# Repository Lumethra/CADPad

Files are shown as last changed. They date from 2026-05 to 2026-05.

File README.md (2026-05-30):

# CADPad

## What is this?? 

SHHH, this is a gift, dont spoiler it, SHHHH. But what exactly is this?? Good question. Its a keyboard. Again. Wait, what does again mean, well its my second one. My [Auth75](https://github.com/Lumethra/Auth75) was my first one. Back to what this is. Its technically a keyboard, but I would rather call it a Macropad, because its firmwares purpose is to make 3d modeling in Onshape easier. This is also why its called a CADPad, not Catpad (meow), CADPad. C A D, like CAD-design. 

### Features: 
  - custom 27 keys leyout
      - its kinda ergonomic? kinda.
  - Nice!Nano V2
      - ZMK firmware (hand written, yeeeeee)
      - better ZMK support, because Nice!Nano V2
      - build in BLE support
      - LiPo battery support
      - battery charger + support
  - USB Hub (SL2.1)
      - 1 USB-C upsream
      - 4 USB-C donwstreams
      - USB 2.0 fullspeed

---

## Why though?

This is a gift to [Chroma](https://github.com/Chroma165), my friend who likes to design 3d-models and print them with his 3d-printer. I though it would be nice to gift him a Macropad, my bad, its a CADPad, to make this process easier for him. It was also fun to design a PCB, that has a unique form. 

---

## How?

This CADPads development process was fairly easiy because of the knowledge from Auth75. It has 3 layers of keybinds, which u can cycle through with pressing the 2nd knob. The other knobs keypress is reserved for BLE pairing. 

---

## Renders

| PCB with Components |
| --- |
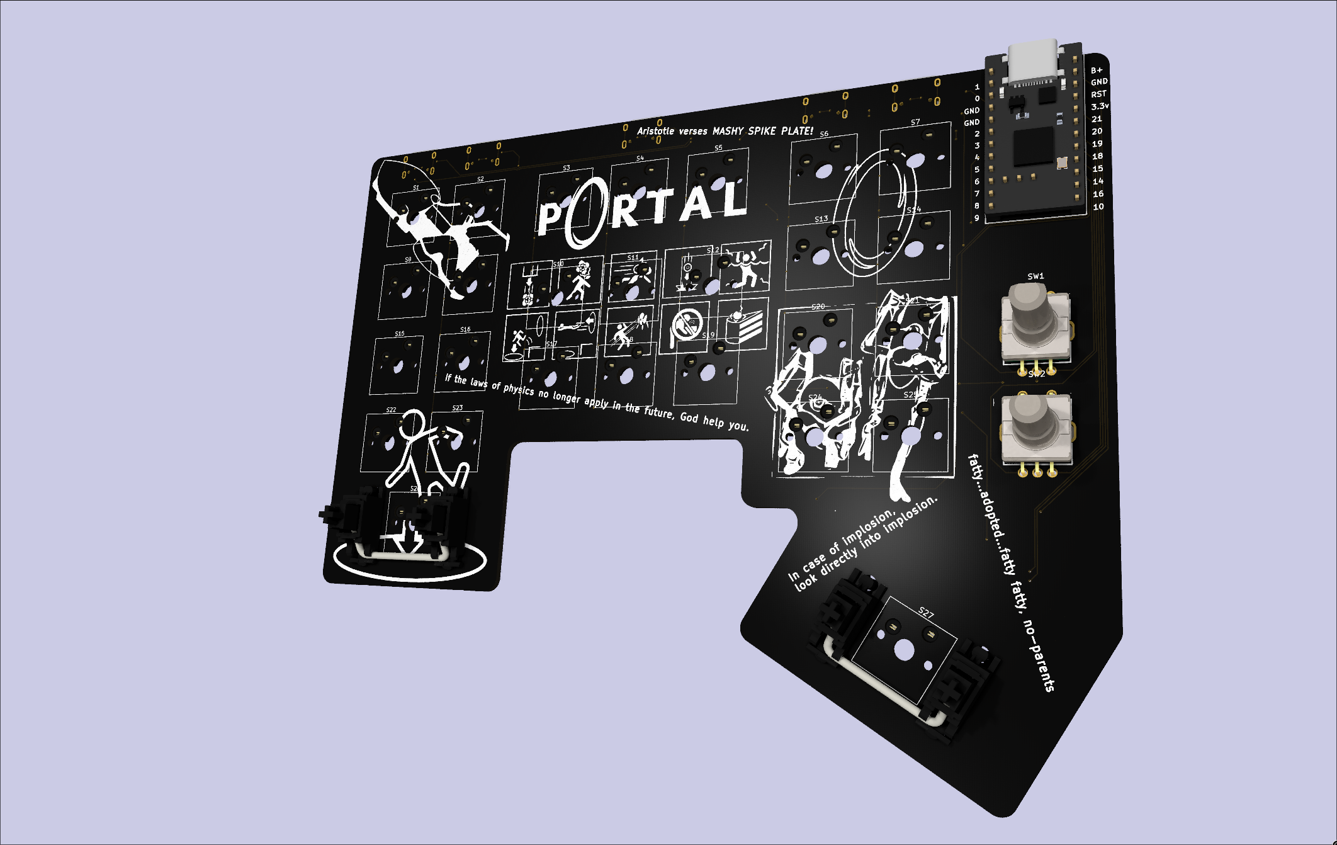
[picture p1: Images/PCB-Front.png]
PCB Front
|  |
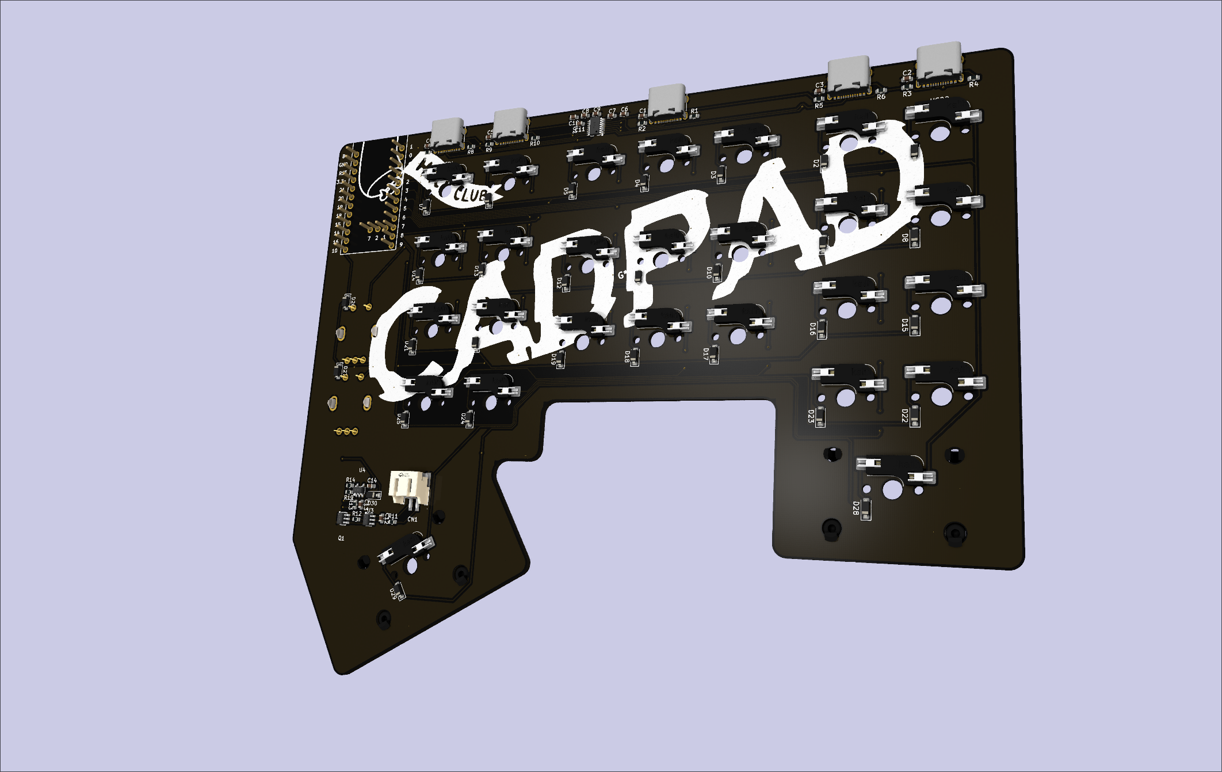
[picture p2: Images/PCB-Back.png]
|  |

| PCB without Components |
| --- |
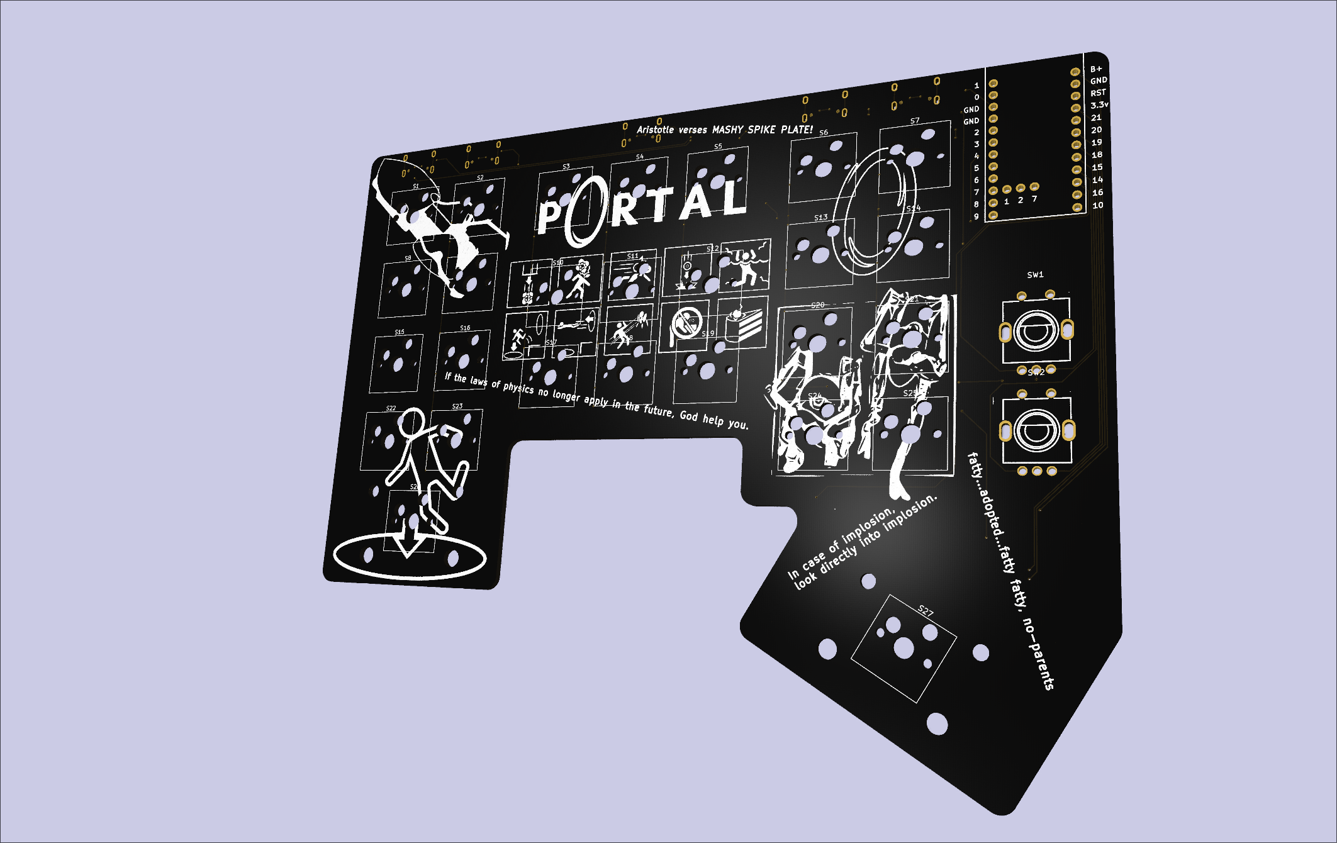
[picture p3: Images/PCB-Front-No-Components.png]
PCB Front
|  |
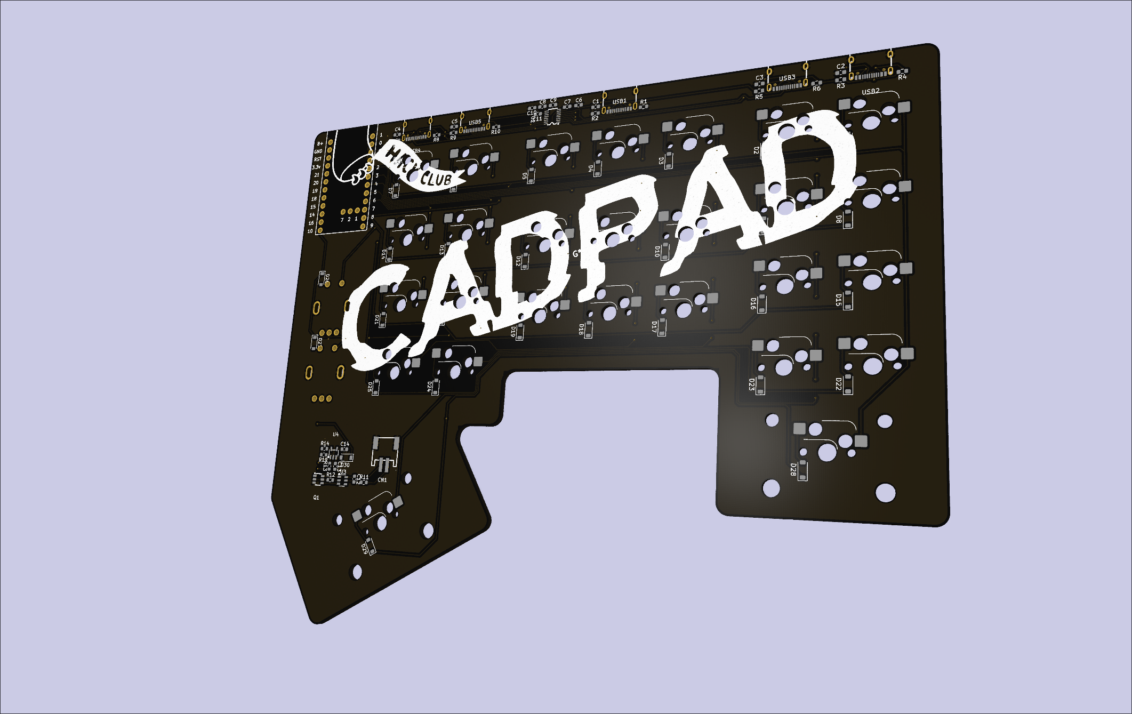
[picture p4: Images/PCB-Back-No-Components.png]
|  |

| Case |
| --- |
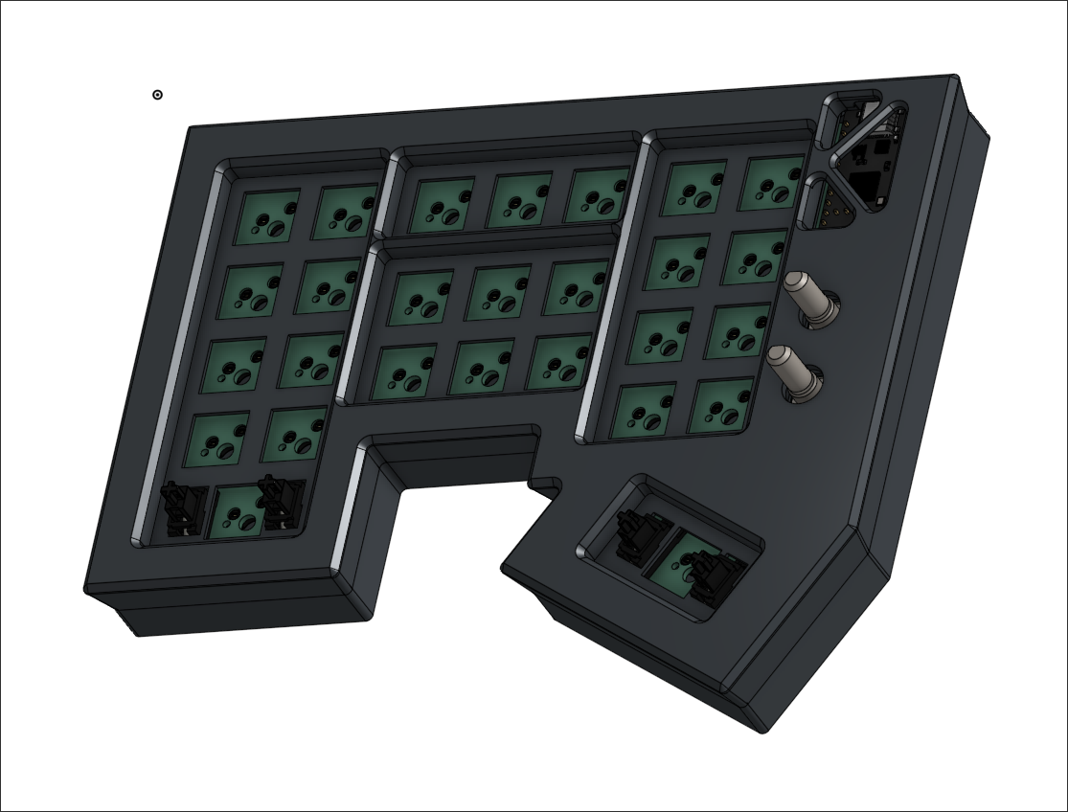
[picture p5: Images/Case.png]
|  |

---

## PCB + Schematics

| PCB |
| --- |
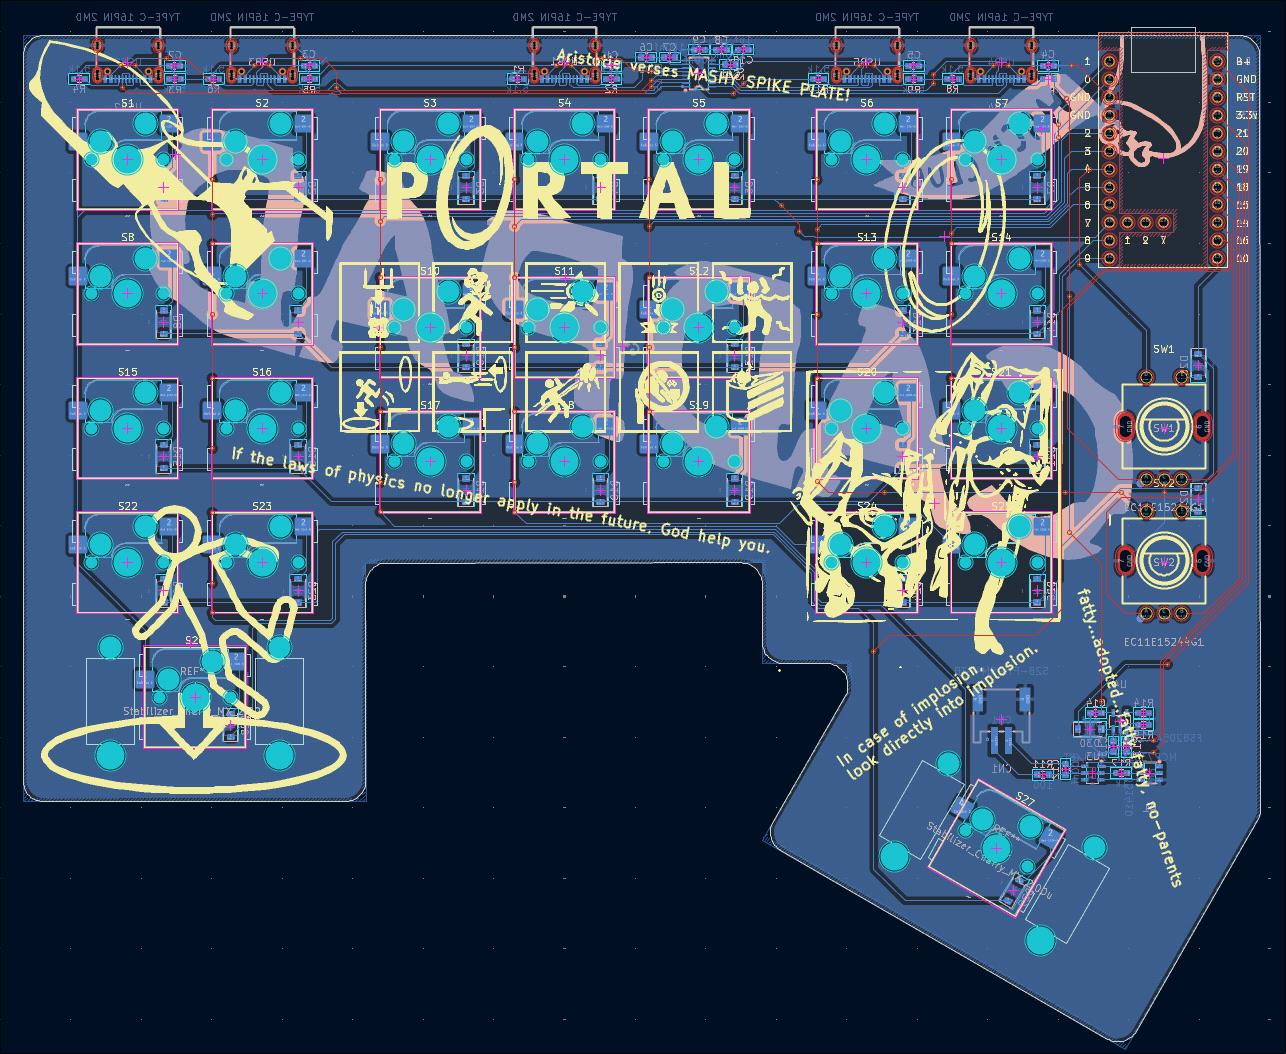
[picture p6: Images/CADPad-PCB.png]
CADPad PCB
|  |

| Schematics |
| --- |
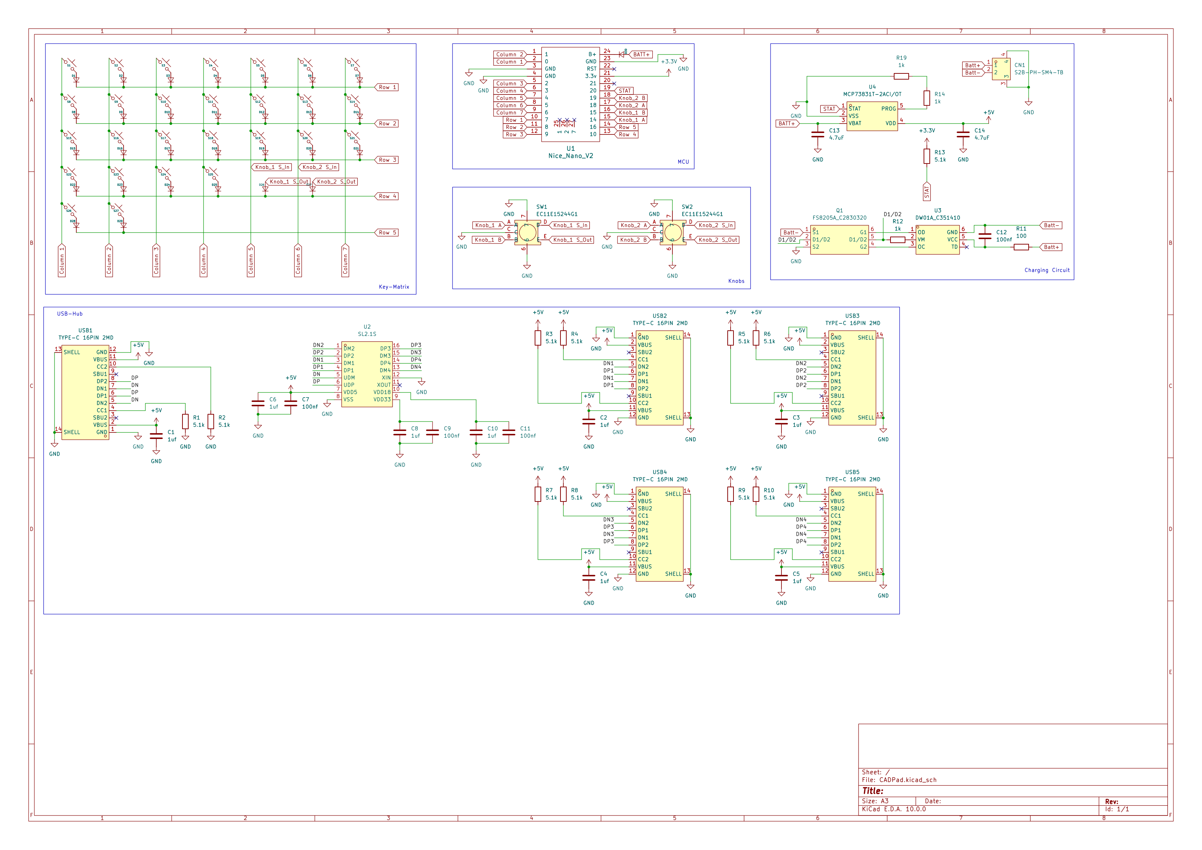
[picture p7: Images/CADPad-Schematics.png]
CADPad Schematics
|  |

---

<details>
  <summary>
    <h2>Zine</h2> 
  </summary>

| Zine |
| --- |
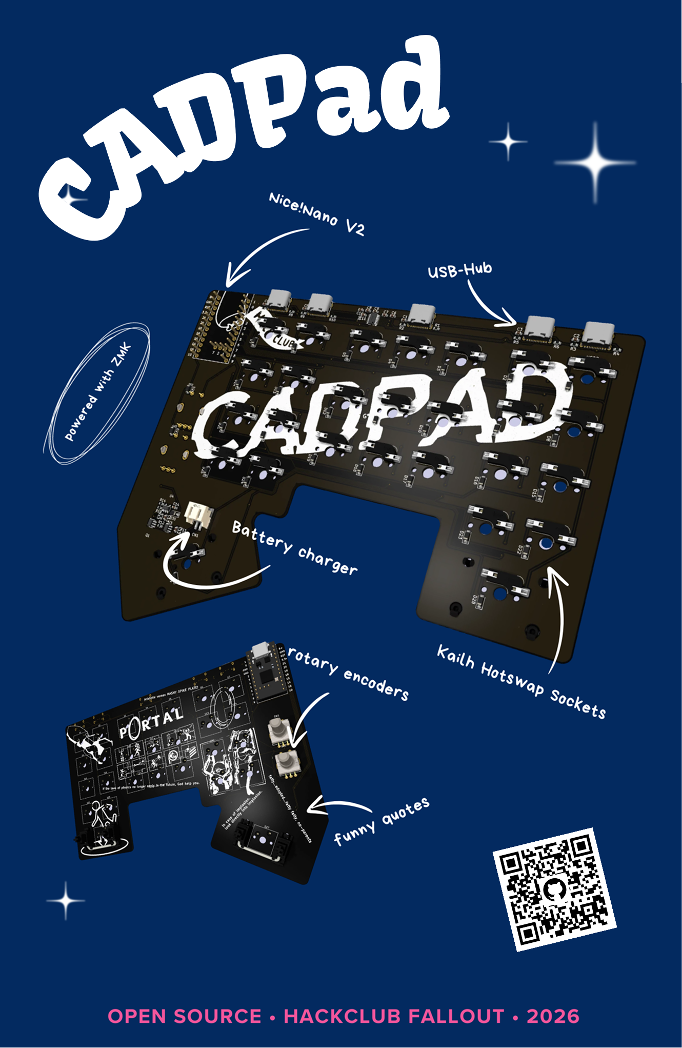
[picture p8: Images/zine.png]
CADPad Zine
|  |

---
</details>

## BOM

| Part | Purpose | Cost | Quantity | Total Cost | LCSC/JLCPC Number | Link |
| --- | --- | --- | --- | --- | --- | --- |
| PCB | connect all of the compoenents | $14.10 | 1 (5) | $14.10 | ~ | [JLCPCB](https://jlcpcb.com/) |
| Nice!Nano V2 | handle the firmware | €24.63 | 1 | €24.63 | ~ | [42keebs](https://42keebs.eu/shop/parts/controllers/nice-nano-v2-wireless-controller/) | 
| Kailh Hotswap Sockets | holding the switches to the PCB without soldering | $0.1183 | 78 | ~$9 | C2803348 | [JLCPCB](https://jlcpcb.com/partdetail/C2803348) |
| Kailh (Cocoa) Switches | the switches you can press | $0 (comes with a Rainy75) | 78 | $0 (already owned) | ~ | ~ |
| Keycaps | goes onto the switches for better look and feel | $0 (3d printing ABS) | 78 | $0 (3d printed) | ~ | ~ |
| EC11 Rotary Encoder Switch | goes uii and click click | $2.22 | 1 | $2.22 | C370970 | [JLCPCB](https://jlcpcb.com/partdetail/C370970) / [Amazon](https://www.amazon.de/-/en/RUNCCI-YUN-Potentiometer-Automotive-Electronics-Multimedia/dp/B09SG3HF9N) |
| USB-C connector | connect to laptop | $0.0740 | 4 | $0.296 | C2765186 | [JLCPCB](https://jlcpcb.com/partdetail/C2765186) |
| SL2.1s | USB Hub core component | $0.2258 | 1 | $0.2258 | C2684433 | [JLCPCB](https://jlcpcb.com/partdetail/C2684433) |
| DW01A | battery protector | $0.0426 | 1 | $0.0426 | C351410 | [JLCPCB](https://jlcpcb.com/partdetail/C351410) |
| FS8205A | mosfet for protector | $0.0470 | 1 | $0.0470 | C2830320 | [JLCPCB](https://jlcpcb.com/partdetail/C2830320) |
| S2B-PH-SM4-TB | LiPo battery connector | $0.2014 | 1 | $0.2014 | C295747 | [JLCPCB](https://jlcpcb.com/partdetail/C295747) |
| Diodes | prevent voltage from backflowing and causing problems | $0.0117 | 82 | ~$0.9594 | C81598 | [JLCPCB](https://jlcpcb.com/partdetail/C81598) |
| Resistors | prevent things go boom | ~$0.0016 | 19 | ~$0.0304 | C23186, C21190, C22775 | [C23186](https://jlcpcb.com/partdetail/C23186) / [C21190](https://jlcpcb.com/partdetail/C21190) / [C22775](https://jlcpcb.com/partdetail/C22775) |
| Capacitors | smooth out the power | $0.0032 - $0.0110 | 14 | ~$0.0956 | C15849, C19666, C14663 | [C15849](https://jlcpcb.com/partdetail/C15849) / [C19666](https://jlcpcb.com/partdetail/C19666) / [C14663](https://jlcpcb.com/partdetail/C14663) |

> the prices can vary depending on the provider <br>
> you can find the JLCPCB parts on [LCSC](https://lcsc.com/) too (exept the PCB and the Pico)

--- 

## Contribute

Want to make anything better? Found any bugs? Anything always going booom?? Feel free to open a PR (pull request) and lets make the project better. ^_^
> the libraries are all imported with [easyeda2kicad](https://github.com/uPesy/easyeda2kicad.py) and [kiswitch](https://github.com/kiswitch/kiswitch)

---

## Thank you

A huge thank you too all these persons helping me making this project possible, thank you helping me sanity check, thank you for all these support. 
> Thank you, <3 u all ^_^

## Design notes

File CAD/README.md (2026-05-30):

Case source files are here

https://cad.onshape.com/documents/18ff7c1247dc01870b6e44be/w/b77948019c848fef9af64c41/e/35ab0d3820c1c6a5cbac0af8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

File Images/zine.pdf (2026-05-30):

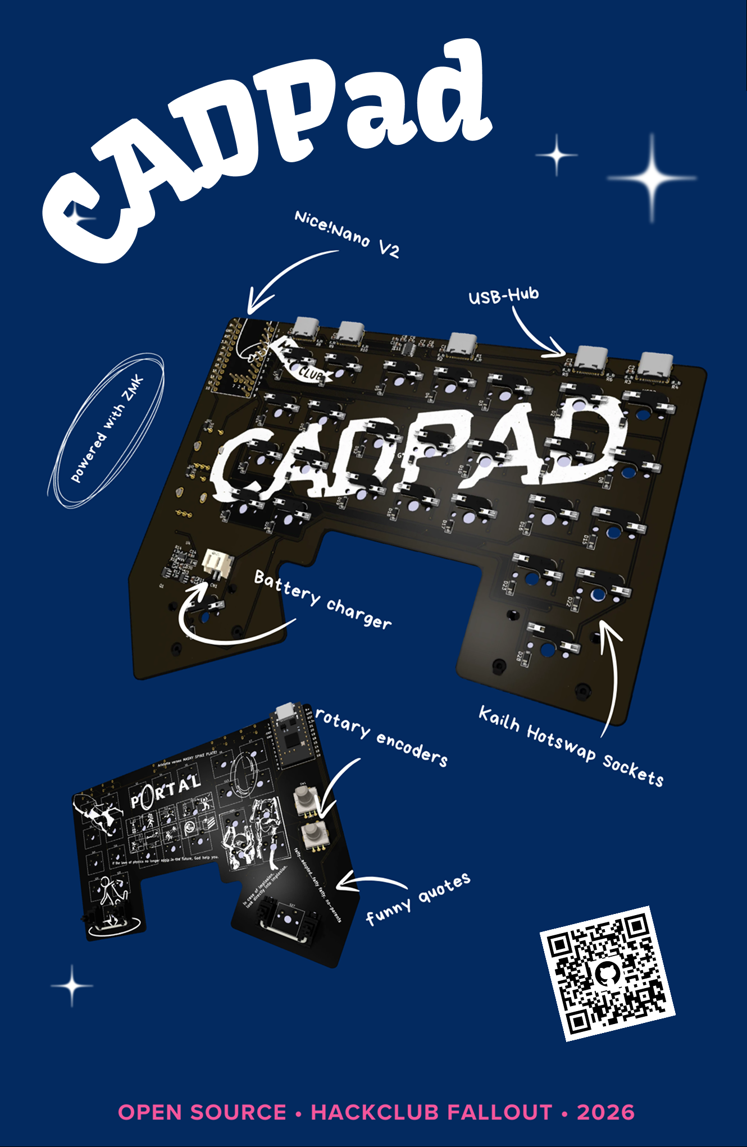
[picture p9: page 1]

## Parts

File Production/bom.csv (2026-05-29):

Name | Designator | Footprint | Quantity | Value | Price | LCSC Part # | Purchase Link
Capacitors 1uF | C1, C10, C2, C3, C4, C5, C6, C8 | 0603 | 8 | 1uF | $0.0032 | C15849 | https://jlcpcb.com/partdetail/C15849
Capacitors 100nF | C11, C12, C7, C9 | 0603 | 4 | 100nF | $0.0032 | C14663 | https://jlcpcb.com/partdetail/C14663
Capacitors 4.7uF | C13, C14 | 0603 | 2 | 4.7uF | $0.0110 | C19666 | https://jlcpcb.com/partdetail/C19666
S2B-PH-SM4-TB | CN1 | CONN-SMD_P2.00_S2B-PH-SM4-TB-LF-SN | 1 | S2B-PH-SM4-TB | $0.2014 | C295747 | https://jlcpcb.com/partdetail/C295747
Diodes | D1, D10, D11, D12, D13, D14, D15, D16, D17, D18, D19, D2, D20, D21, D22, D23, D24, D25, D26, D27, D28, D29, D3, D30, D4, D5, D6, D7, D8, D9 | D_SOD-123 | 30 | ~ | $0.0117 | C81598 | https://jlcpcb.com/partdetail/C81598
FS8205A | Q1 | SOT-23-6_L2.9-W1.6-P0.95-LS2.8-BR | 1 | FS8205A_C2830320 | $0.0470 | C2830320 | https://jlcpcb.com/partdetail/C2830320
Resistors 5.1k | R1, R10, R13, R2, R3, R4, R5, R6, R7, R8, R9 | 0603 | 11 | 5.1k | $0.0016 | C23186 | https://jlcpcb.com/partdetail/C23186
Resistors 100 | R11 | 0603 | 1 | 100 | $0.0016 | C22775 | https://jlcpcb.com/partdetail/C22775
Resistors 1k | R12, R14, R19 | 0603 | 3 | 1k | $0.0016 | C21190 | https://jlcpcb.com/partdetail/C21190
Kailh Hotswap Sockets | S1, S10, S11, S12, S13, S14, S15, S16, S17, S18, S19, S2, S20, S21, S22, S23, S24, S25, S26, S27, S3, S4, S5, S6, S7, S8, S9 | SW_Hotswap_Kailh_MX | 27 | ~ | $0.1183 | C2803348 | https://jlcpcb.com/partdetail/C2803348
Nice Nano V2 | U1 | Nice_Nano_V2 | 1 | Nice_Nano_V2 | €24.63 | ~ | https://42keebs.eu/shop/parts/controllers/nice-nano-v2-wireless-controller/
SL2.1S | U2 | SSOP-16_L4.6-W2.6-P0.53-LS4.0-BL | 1 | SL2.1S | $0.2258 | C2684433 | https://jlcpcb.com/partdetail/C2684433
DW01A | U3 | SOT-23-6_L2.9-W1.6-P0.95-LS2.8-BL | 1 | DW01A_C351410 | $0.0426 | C351410 | https://jlcpcb.com/partdetail/C351410
MCP73831T-2ACI/OT | U4 | SOT-23-5_L3.0-W1.7-P0.95-LS2.8-BL | 1 | MCP73831T-2ACI/OT | $0.7585 | C424093 | https://jlcpcb.com/partdetail/C424093
USB-C Connector | USB1, USB2, USB3, USB4, USB5 | USB-C-SMD_TYPE-C-6PIN-2MD-073 | 5 | TYPE-C 16PIN 2MD | $0.0740 | C2765186 | https://jlcpcb.com/partdetail/C2765186

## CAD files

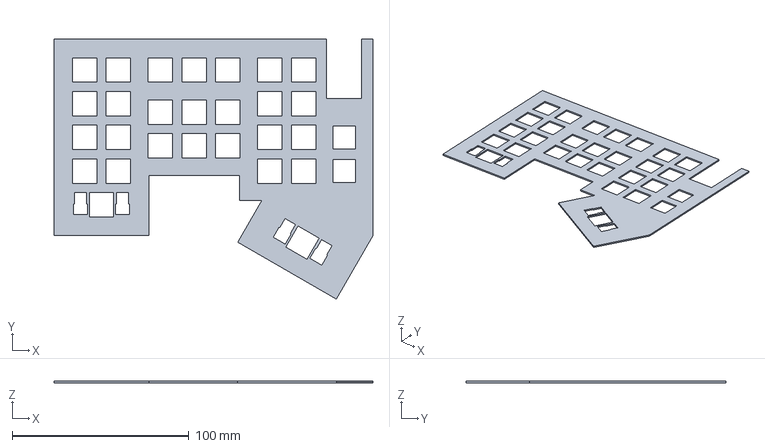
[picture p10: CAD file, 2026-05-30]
CAD/Case/CadPadSwitchPlate.step
180.4 x 147.2 x 1.00 mm

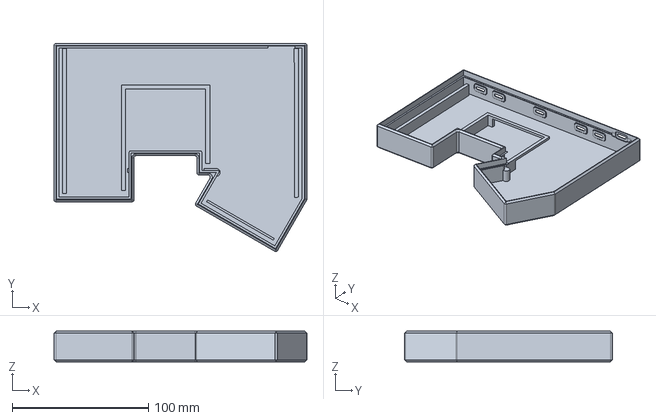
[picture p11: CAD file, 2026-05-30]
CAD/Case/CadPadBottomHalf.step
185.4 x 152.6 x 22.4 mm

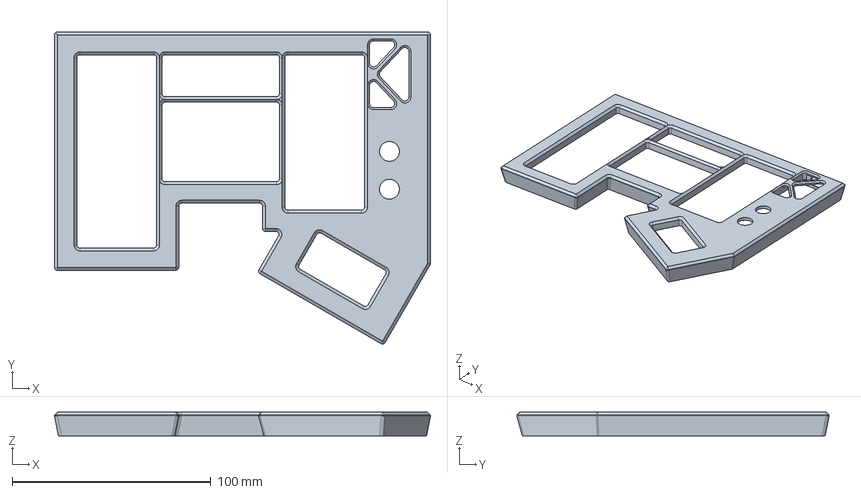
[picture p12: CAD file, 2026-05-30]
CAD/Case/CadPadTopHalf.step
189.4 x 157.3 x 12.1 mm

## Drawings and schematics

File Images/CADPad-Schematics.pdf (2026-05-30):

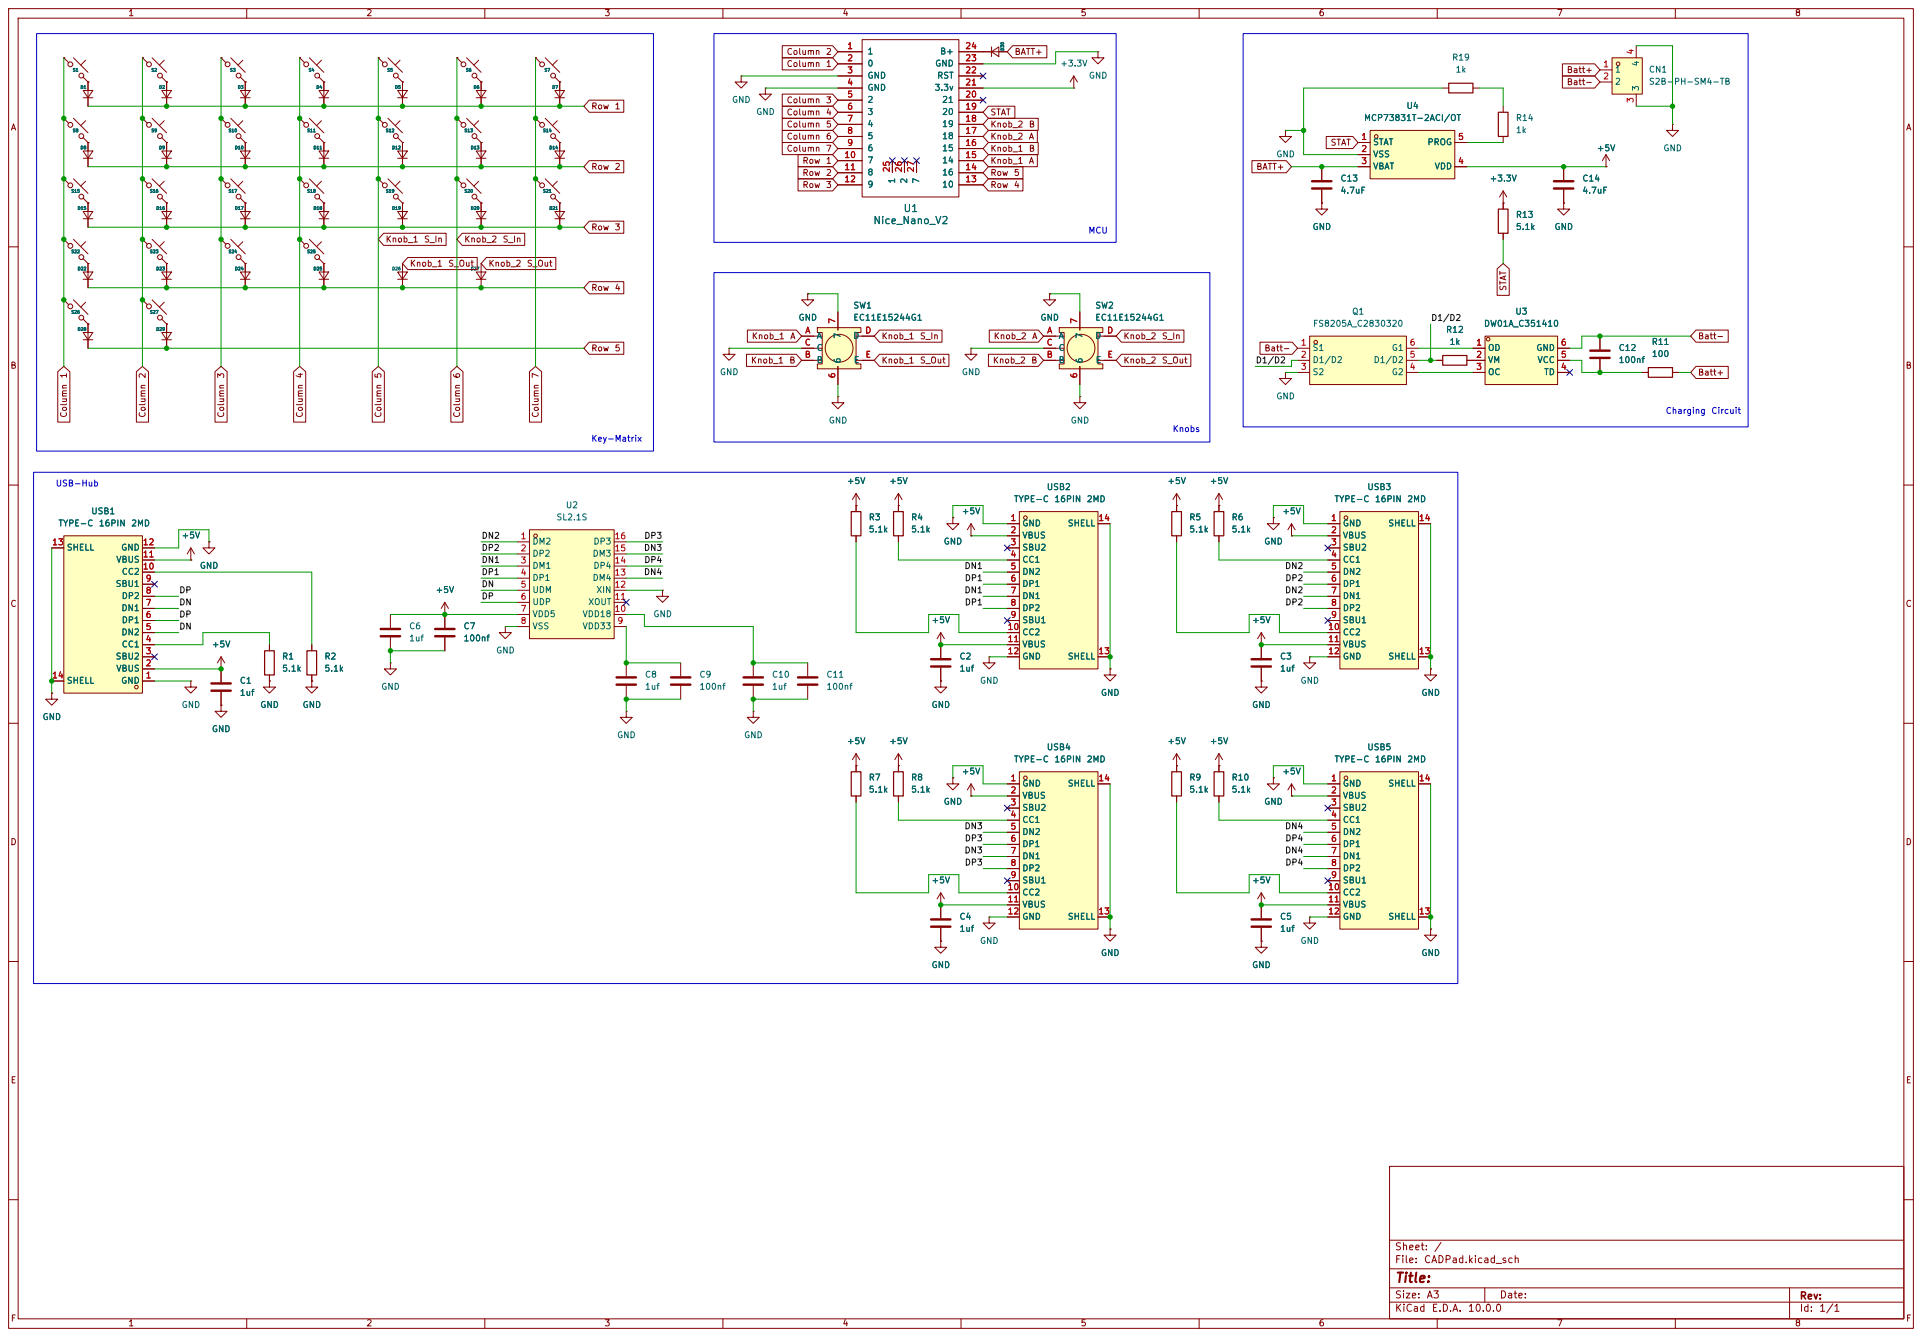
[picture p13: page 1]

Size: A3 | Rev: | F Date:
KiCad E.D.A. 10.0.0 | Id: 1/1

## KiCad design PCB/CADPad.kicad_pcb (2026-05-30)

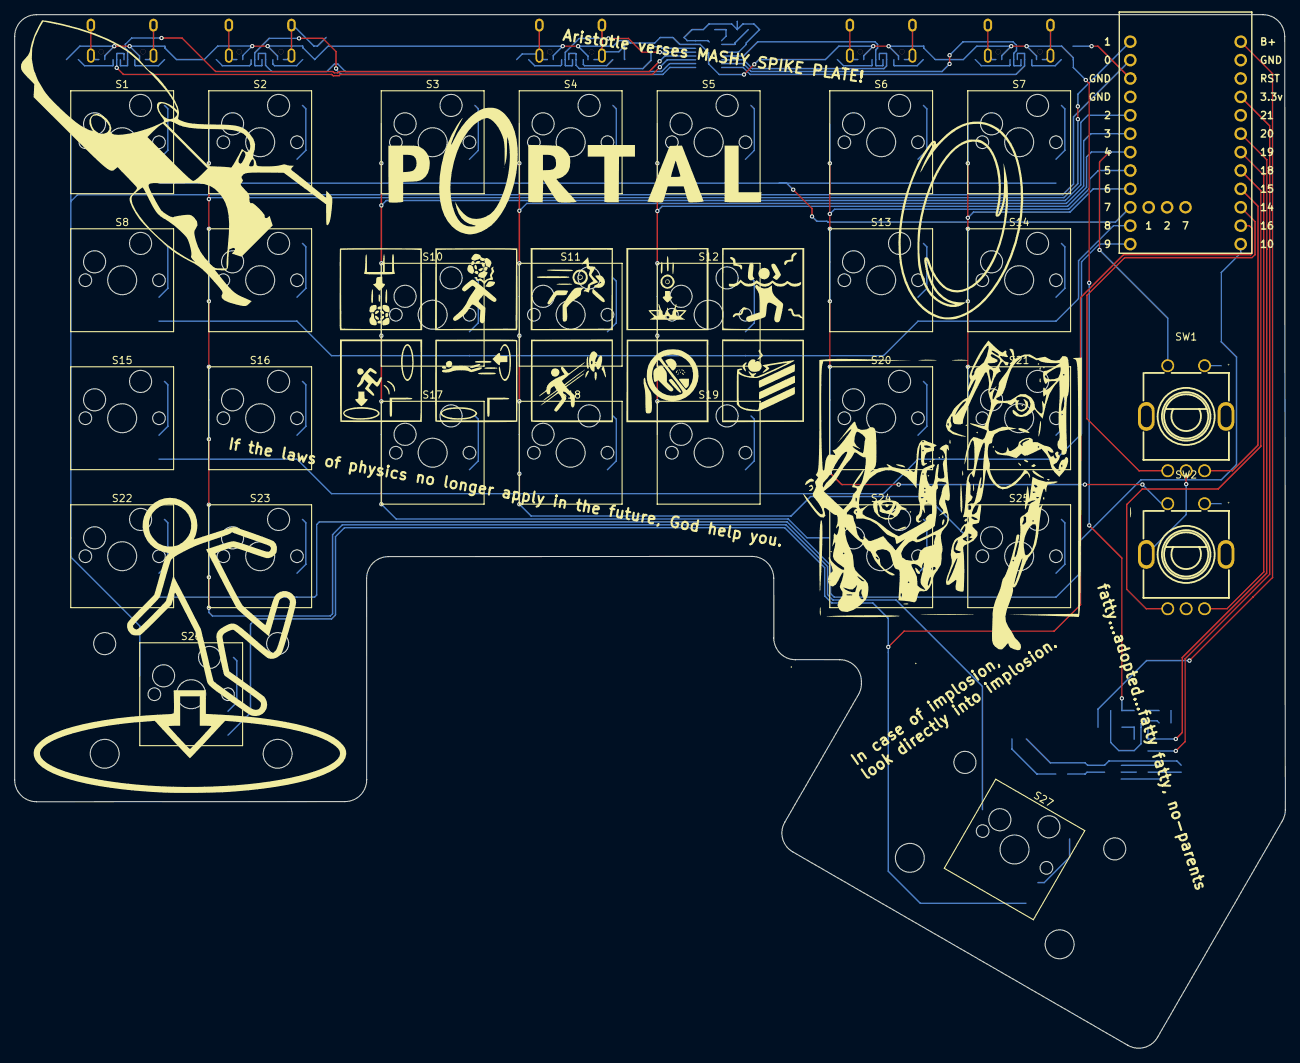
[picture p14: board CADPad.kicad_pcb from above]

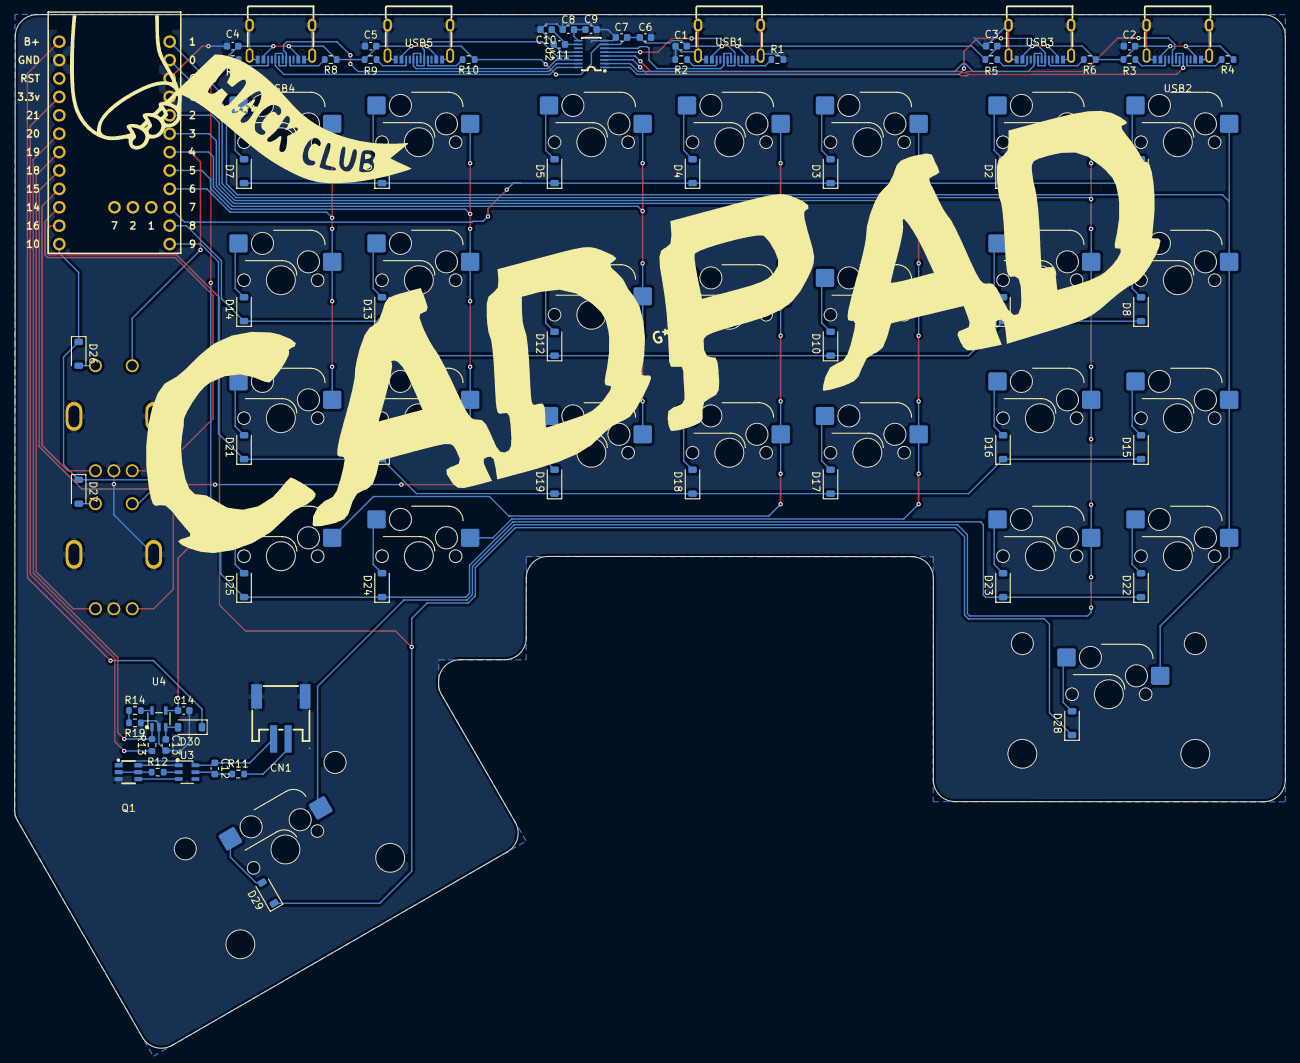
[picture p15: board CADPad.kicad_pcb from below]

Board: 2 copper layers, 175.4 x 142.7 mm, 99 parts (69 on the bottom side), 82 nets.

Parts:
C1, C2, C3, C4, C5, C6, C8, C10: 1uf; C_0603_1608Metric
C7, C9, C11, C12: 100nf; C_0603_1608Metric
C13, C14: 4.7uF; C_0603_1608Metric
CN1: S2B-PH-SM4-TB; CONN-SMD_P2.00_S2B-PH-SM4-TB-LF-SN
D1, D2, D3, D4, D5, D6, D7, D8, D9, D10, D11, D12, D13, D14, D15, D16, D17, D18, D19, D20, D21, D22, D23, D24, D25, D26, D27, D28, D29, D30: D_SOD-123
Q1: FS8205A_C2830320; SOT-23-6_L2.9-W1.6-P0.95-LS2.8-BR
R1, R2, R3, R4, R5, R6, R7, R8, R9, R10, R13: 5.1k; R_0603_1608Metric
R11: 100; R_0603_1608Metric
R12, R14, R19: 1k; R_0603_1608Metric
S1, S2, S3, S4, S5, S6, S7, S8, S9, S10, S11, S12, S13, S14, S15, S16, S17, S18, S19, S20, S21, S22, S23, S24, S25, S26, S27: SW_Hotswap_Kailh_MX
SW1, SW2: EC11E15244G1; SW-TH_EC11E15244G1
U1: Nice_Nano_V2
U2: SL2.1S; SSOP-16_L4.6-W2.6-P0.53-LS4.0-BL
U3: DW01A_C351410; SOT-23-6_L2.9-W1.6-P0.95-LS2.8-BL
U4: MCP73831T-2ACI/OT; SOT-23-5_L3.0-W1.7-P0.95-LS2.8-BL
USB1, USB2, USB3, USB4, USB5: TYPE-C 16PIN 2MD; USB-C-SMD_TYPE-C-6PIN-2MD-073

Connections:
+3.3V: R13.1, U1.21 (3.3v)
+5V: C1.1, C2.1, C3.1, C4.1, C5.1, C6.1, C7.1, C14.1, R3.1, R4.1, R5.1, R6.1, R7.1, R8.1, R9.1, R10.1, U2.7 (VDD5), U4.4 (VDD), USB1.2 (VBUS), USB1.11 (VBUS), USB2.2 (VBUS), USB2.11 (VBUS), USB3.2 (VBUS), USB3.11 (VBUS), USB4.2 (VBUS), USB4.11 (VBUS), USB5.2 (VBUS), USB5.11 (VBUS)
/D1/D2: Q1.2 (D1/D2), Q1.5 (D1/D2), R12.1
/DN: U2.5 (UDM), USB1.5 (DN2), USB1.7 (DN1)
/DN1: U2.3 (DM1), USB2.5 (DN2), USB2.7 (DN1)
/DN2: U2.1 (DM2), USB3.5 (DN2), USB3.7 (DN1)
/DN3: U2.15 (DM3), USB4.5 (DN2), USB4.7 (DN1)
/DN4: U2.13 (DM4), USB5.5 (DN2), USB5.7 (DN1)
/DP: U2.6 (UDP), USB1.6 (DP1), USB1.8 (DP2)
/DP1: U2.4 (DP1), USB2.6 (DP1), USB2.8 (DP2)
/DP2: U2.2 (DP2), USB3.6 (DP1), USB3.8 (DP2)
/DP3: U2.16 (DP3), USB4.6 (DP1), USB4.8 (DP2)
/DP4: U2.14 (DP4), USB5.6 (DP1), USB5.8 (DP2)
BATT+: C13.1, D30.2 (A), U4.3 (VBAT)
Batt+: CN1.1, R11.2
Batt-: C12.1, CN1.2, Q1.1 (S1), U3.6 (GND)
Column 1: S1.1, S8.1, S15.1, S22.1, S26.1, U1.2 (0)
Column 2: S2.1, S9.1, S16.1, S23.1, S27.1, U1.1
Column 3: S3.1, S10.1, S17.1, S24.1, U1.5 (2)
Column 4: S4.1, S11.1, S18.1, S25.1, U1.6 (3)
Column 5: S5.1, S12.1, S19.1, SW1.D, U1.7 (4)
Column 6: S6.1, S13.1, S20.1, SW2.D, U1.8 (5)
Column 7: S7.1, S14.1, S21.1, U1.9 (6)
GND: C1.2, C2.2, C3.2, C4.2, C5.2, C6.2, C7.2, C8.2, C9.2, C10.2, C11.2, C13.2, C14.2, CN1.3, CN1.4, Q1.3 (S2), R1.2, R2.2, R19.1, SW1.6, SW1.7, SW1.C, SW2.6, SW2.7, SW2.C, U1.3 (GND), U1.4 (GND), U1.23 (GND), U2.8 (VSS), U2.12 (XIN), U4.2 (VSS), USB1.1 (GND), USB1.12 (GND), USB1.13 (SHELL), USB1.14 (SHELL), USB2.1 (GND), USB2.12 (GND), USB2.13 (SHELL), USB2.14 (SHELL), USB3.1 (GND), USB3.12 (GND), USB3.13 (SHELL), USB3.14 (SHELL), USB4.1 (GND), USB4.12 (GND), USB4.13 (SHELL), USB4.14 (SHELL), USB5.1 (GND), USB5.12 (GND), USB5.13 (SHELL), USB5.14 (SHELL)
Knob_1 A: SW1.A, U1.15 (14)
Knob_1 B: SW1.B, U1.16 (15)
Knob_1 S_Out: D26.2 (A), SW1.E
Knob_2 A: SW2.A, U1.17 (18)
Knob_2 B: SW2.B, U1.18 (19)
Knob_2 S_Out: D27.2 (A), SW2.E
unnamed: D1.2 (A), S1.2
unnamed: D2.2 (A), S2.2
unnamed: D3.2 (A), S3.2
unnamed: D4.2 (A), S4.2
unnamed: D5.2 (A), S5.2
unnamed: D6.2 (A), S6.2
unnamed: D7.2 (A), S7.2
unnamed: D8.2 (A), S8.2
unnamed: D9.2 (A), S9.2
unnamed: D10.2 (A), S10.2
unnamed: D11.2 (A), S11.2
unnamed: D12.2 (A), S12.2
unnamed: D13.2 (A), S13.2
unnamed: D14.2 (A), S14.2
unnamed: D15.2 (A), S15.2
unnamed: D16.2 (A), S16.2
unnamed: D17.2 (A), S17.2
unnamed: D18.2 (A), S18.2
unnamed: D19.2 (A), S19.2
unnamed: D20.2 (A), S20.2
unnamed: D21.2 (A), S21.2
unnamed: D22.2 (A), S22.2
unnamed: D23.2 (A), S23.2
unnamed: D24.2 (A), S24.2
unnamed: D25.2 (A), S25.2
unnamed: D28.2 (A), S26.2
unnamed: D29.2 (A), S27.2
unnamed: D30.1 (K), U1.24 (B+)
unnamed: Q1.6 (G1), U3.1 (OD)
unnamed: Q1.4 (G2), U3.3 (OC)
unnamed: R14.1, R19.2
unnamed: C10.1, C11.1, U2.10 (VDD18)
unnamed: C8.1, C9.1, U2.9 (VDD33)
unnamed: C12.2, R11.1, U3.5 (VCC)
unnamed: R12.2, U3.2 (VM)
unnamed: R14.2, U4.5 (PROG)
unnamed: R1.1, USB1.4 (CC1)
unnamed: R2.1, USB1.10 (CC2)
unnamed: R4.2, USB2.4 (CC1)
unnamed: R3.2, USB2.10 (CC2)
unnamed: R6.2, USB3.4 (CC1)
unnamed: R5.2, USB3.10 (CC2)
unnamed: R8.2, USB4.4 (CC1)
unnamed: R7.2, USB4.10 (CC2)
unnamed: R10.2, USB5.4 (CC1)
unnamed: R9.2, USB5.10 (CC2)
Row 1: D1.1 (K), D2.1 (K), D3.1 (K), D4.1 (K), D5.1 (K), D6.1 (K), D7.1 (K), U1.10 (7)
Row 2: D8.1 (K), D9.1 (K), D10.1 (K), D11.1 (K), D12.1 (K), D13.1 (K), D14.1 (K), U1.11 (8)
Row 3: D15.1 (K), D16.1 (K), D17.1 (K), D18.1 (K), D19.1 (K), D20.1 (K), D21.1 (K), U1.12 (9)
Row 4: D22.1 (K), D23.1 (K), D24.1 (K), D25.1 (K), D26.1 (K), D27.1 (K), U1.13 (10)
Row 5: D28.1 (K), D29.1 (K), U1.14 (16)
STAT: R13.2, U1.19 (20), U4.1 (STAT)

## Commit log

2026-05-22 Create Project
    [CADPad.kicad_pcb, CADPad.kicad_sch]
2026-05-29 adding firmware (note: its a seperate repo)
    [CADPad.kicad_pcb, bom.csv, designators.csv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]
2026-05-29 assigning LSCS numbers and regenerating PCB-CAD
    [CADPad.kicad_pcb, CADPad.kicad_sch]
2026-05-29 enhance BOM
    [CADPad.kicad_pcb, CADPad.kicad_sch, bom.csv]
2026-05-29 enhance again (minor)
    [bom.csv]
2026-05-30 add images
    [CADPad.kicad_pcb]
2026-05-30 case 3d render
2026-05-30 adding Case
